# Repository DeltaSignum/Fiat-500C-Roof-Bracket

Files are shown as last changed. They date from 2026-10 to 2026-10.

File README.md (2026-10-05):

# Fiat 500C Roof Bracket - No Disassembly Fix

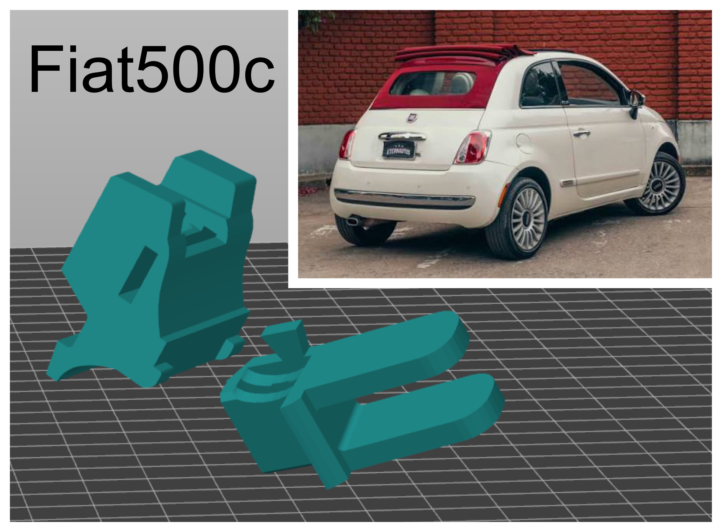
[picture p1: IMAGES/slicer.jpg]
Brackets - Inner, Outer


Common Fiat 500C (2009-present) failure - original plastic brackets crumble after sun exposure. Dealer fix = remove entire roof, 500-800€.

### This fix
- 2-part bracket that clips from both sides
- Flat locking bar that locks it - no glue needed (glue melts at 85°C on black roof, tested in Canary Islands)
- No roof disassembly
- Designed from broken originals 2025-02-07

### What to print

- [bracket_inner.stl](STL/bracket_inner.stl) - L/R mirrored in slicer
- [bracket_outer.stl](STL/bracket_outer.stl) - L/R mirrored in slicer

For inter-lock reuses original Fiat metal rod.

### How to print (no chamber)
My setup for ABS without enclosure:
- Full-height skirt as draft shield - creates hot air curtain
- G-code modifier:
    - Fan 0% for layers 1-3 for better adhesion
    - Outer walls: fan 70%
    - Inner walls: fan 0%, flow 105% over-extrusion
    - Hot air recirculation - blower that collects hot air from nozzle and pushes back
- Material: ABS. PETG, PLA softens in summer on black roof.

### Install
1. Remove crumbs of old plastic bracket
2. Slide inner bracket onto the roof support - double tube / rail
3. Slide inner bracket part into outer bracket part
4. Clip outer and inner brackets together - it locks on the metal bar slided in, no glue

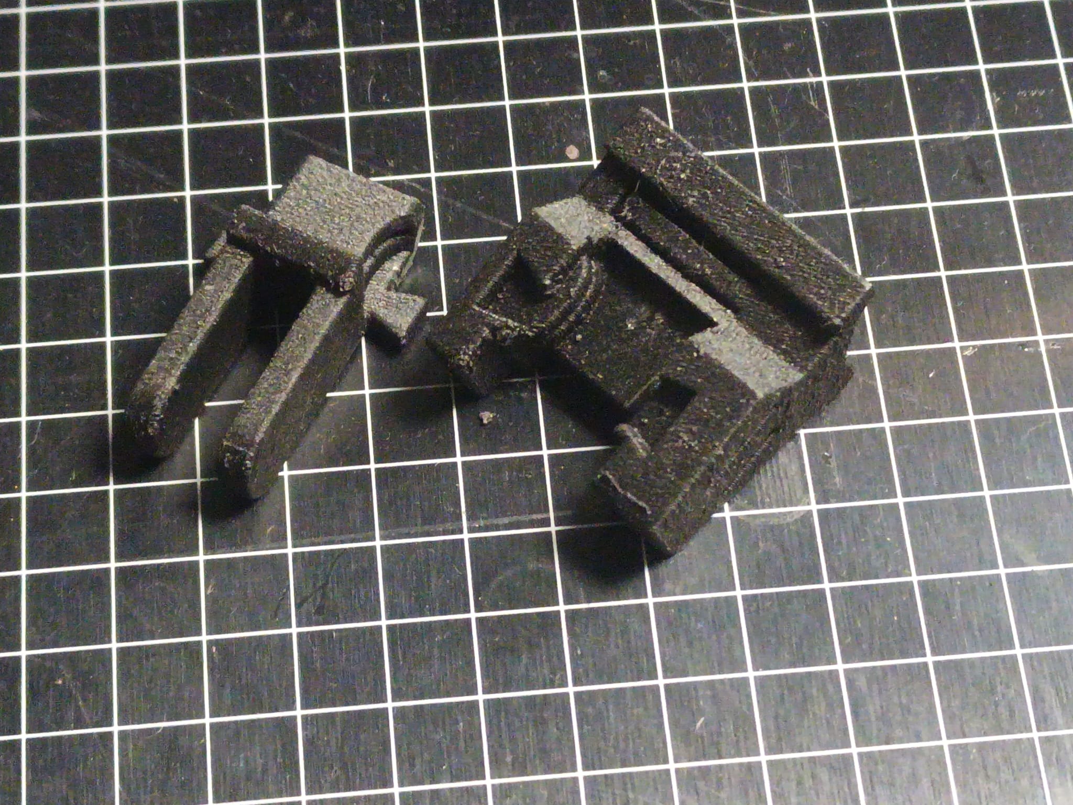
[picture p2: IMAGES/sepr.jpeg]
Fiat500c brackets


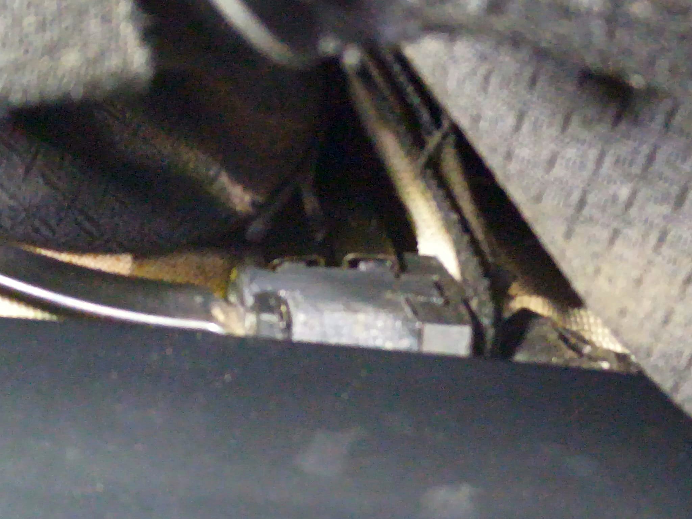
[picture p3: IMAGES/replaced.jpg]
Fiat500c replaced


More functional 3D prints and acoustic projects: https://deltasignum.org
Original acoustic project: DeltaSignum/Dynamic-Zero

### License
【entity-MIT¦canonical_name=MIT】

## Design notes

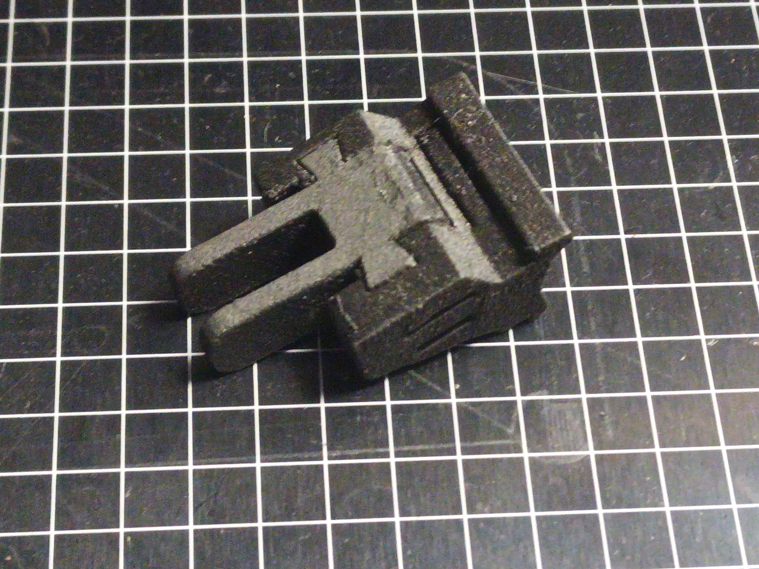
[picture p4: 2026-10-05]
IMAGES/joind.jpeg

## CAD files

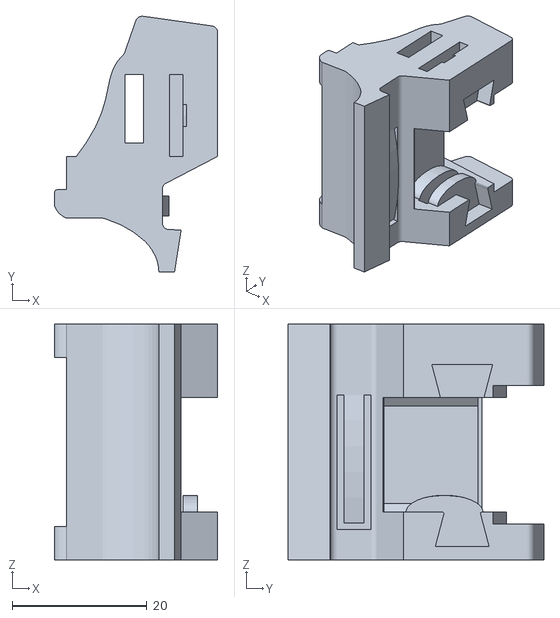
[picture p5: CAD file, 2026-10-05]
STL/bracket_outer.stl
24.2 x 37.9 x 35.0

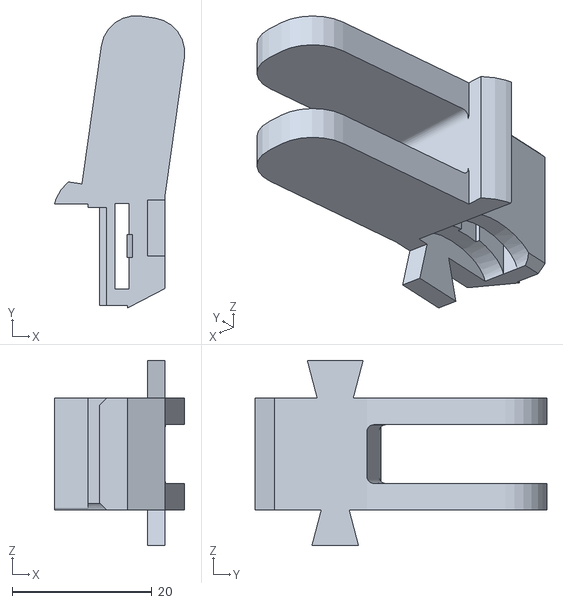
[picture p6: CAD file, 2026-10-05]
STL/bracket_inner.stl
18.6 x 41.7 x 26.5

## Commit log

2026-10-05 Enhance README with detailed fix instructions
    Expanded README to provide detailed instructions and specifications for the Fiat 500C roof bracket fix, including printing guidelines and installation steps.
2026-10-05 Update printing instructions in README.md
    Clarified printing instructions for bracket_inner.stl.
2026-10-05 Update README with images and printing details
    Added images and clarified printing instructions in README.
2026-10-05 Fix image path for brackets in README
    Updated image path for brackets in README.
2026-10-05 Add image of brackets to README
    Added an image of the brackets to the README.
2026-10-05 Update fan settings description in README
    No-disassembly fix for Fiat 500C roof brackets. ABS, no glue.
